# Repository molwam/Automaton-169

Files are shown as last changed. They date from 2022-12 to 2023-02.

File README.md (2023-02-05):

# Automaton 169

This is a wireless low profile split keyboard. It features a 32 key column-staggered and -splayed layout and 3 status LEDs per side. For wireless operation it utilizes a Seeed Studio XIAO nRF52840 running ZMK.

## PCB
Gerber, Kicad Files, BOM and order and assembly instructions are [here](https://github.com/molwam/Automaton-169/tree/main/pcb).

## Firmware
Just flash the left side and right side [fimware ](https://github.com/molwam/zmk-config-automaton-169/tree/main/config) onto the the corresponding side controller. If you want to customize the keymap, clone the repo and adjust the [keymap file](https://github.com/molwam/zmk-config-automaton-169/blob/main/config/boards/shields/automaton169/automaton169.keymap).

## Credits
This keyboard was inspired by the [KLOTZ](https://github.com/GEIGEIGEIST/KLOTZ) by [GEIST](https://github.com/GEIGEIGEIST) and the [midge](https://github.com/jimmerricks/bugs/tree/main/pcbs/midge) by [jmnw](https://github.com/jimmerricks).

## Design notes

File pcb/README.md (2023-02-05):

# PCB
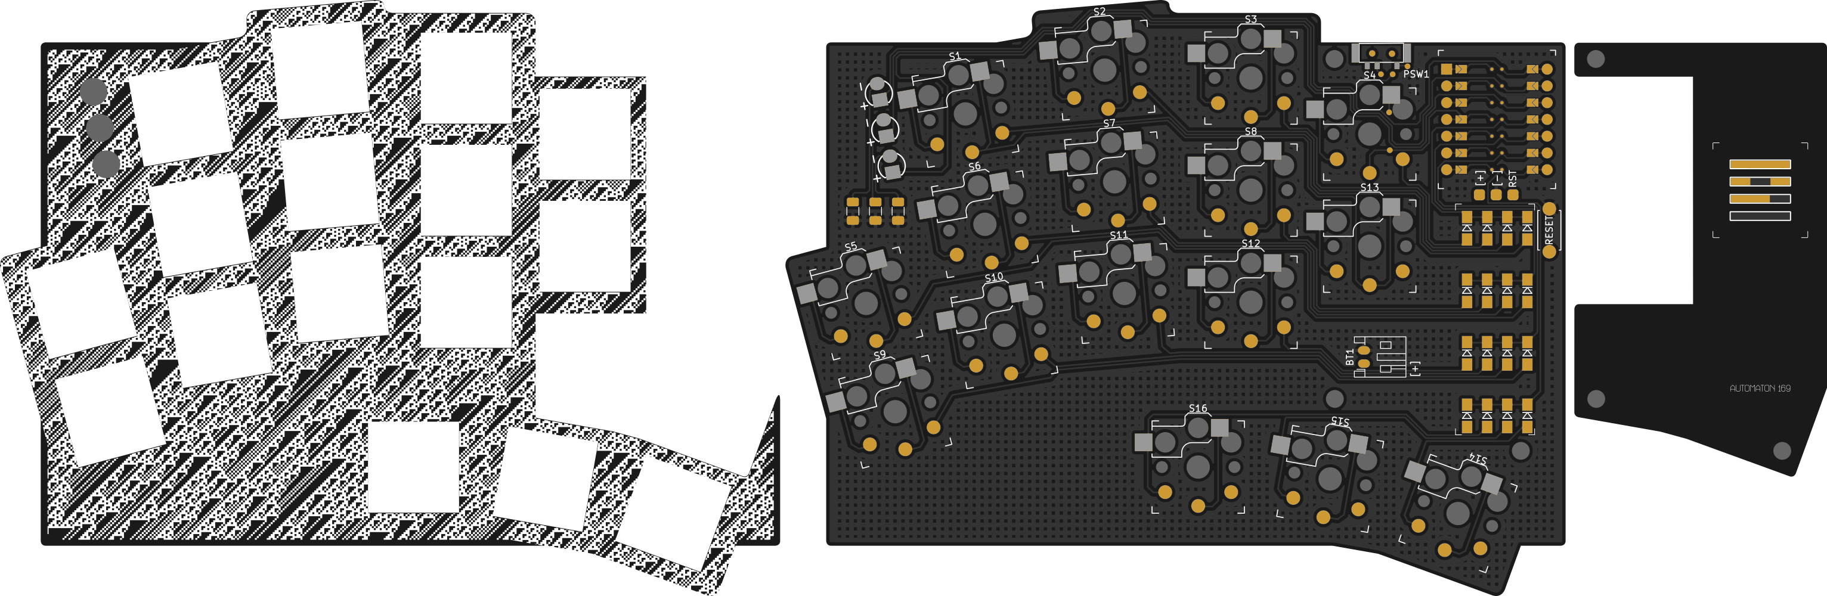
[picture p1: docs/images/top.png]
PCB top

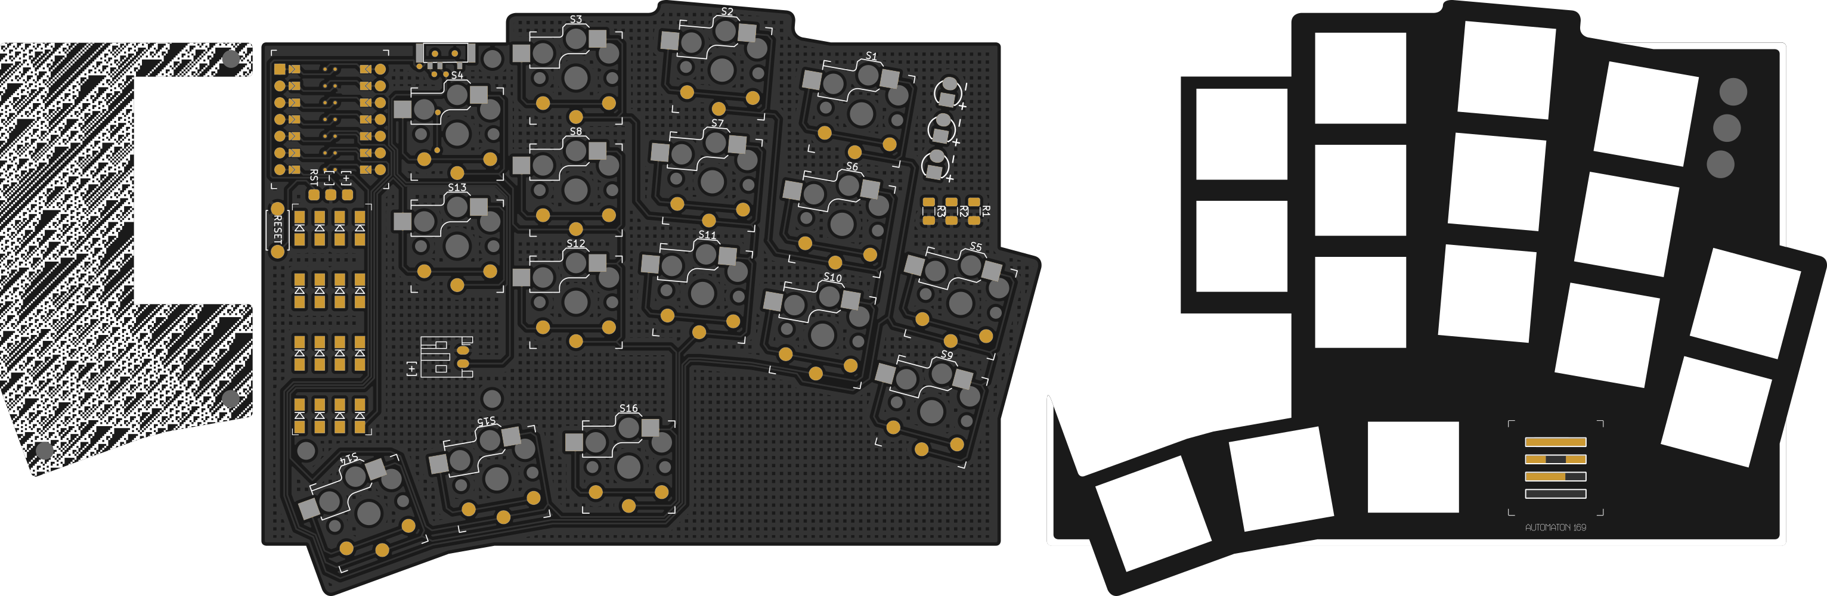
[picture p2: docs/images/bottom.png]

## Ordering

You can use the [gerber.zip](https://github.com/molwam/Automaton-169/blob/main/pcb/gerber.zip) file to order the PCB at your favorite PCB manufacturer. It's reversible so you need to order at least 2. These are the required settings when ordering:

 - Material: FR-4
 - Layers: 2
 - Dimension (Length): 281.40mm
 - Dimension (Width): 90.40mm
 - Separated Different Design: 3*
 - Panelized PCBs: As in my Gerber Files* 
 - PCB Thickness: 1.6mm
 - Copper Thickness: 1 oz
 - Inner Copper Thickness: No
 - FR-4 Material: TG135
 - Min. Traces / Spacing: 6 mil
 - Min. Hole Size: 0.3 mm
 - Edge Plating: No
 - Blind Vias: No
 - Half Cut Holes: No
 - Impedance Control: No

*The PCB is panelized in three Parts: PCB - Switch Plate - Controller and Battery Cover

## Parts needed 

## Assembly

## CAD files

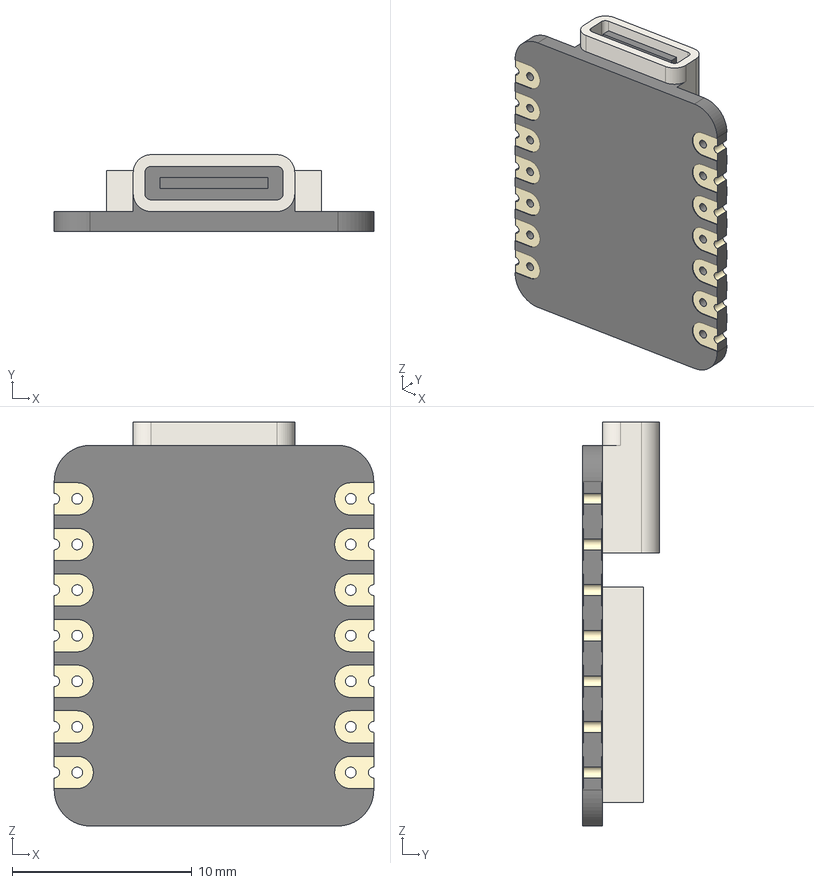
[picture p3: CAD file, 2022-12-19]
pcb/kicad files/3D/xiao-ble-tht.step
17.8 x 4.27 x 22.5 mm

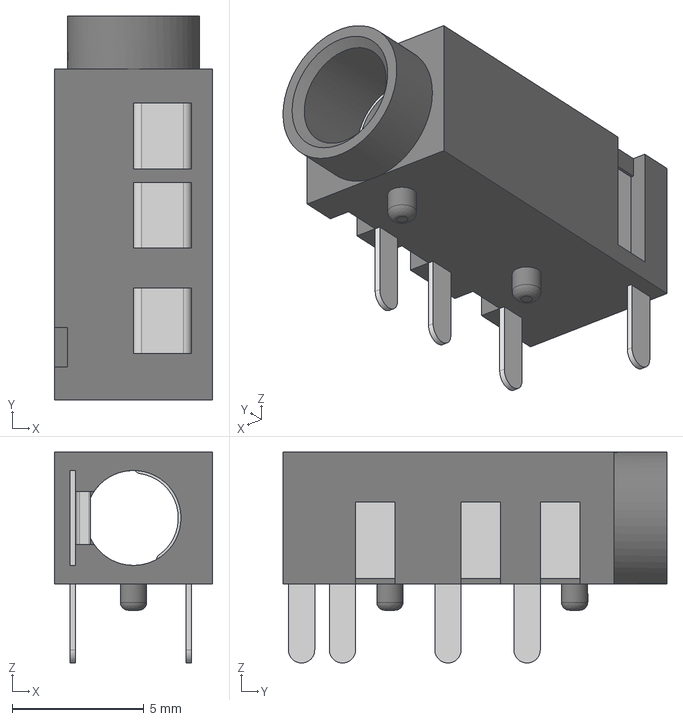
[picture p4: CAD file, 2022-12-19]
pcb/kicad files/3D/PJ320A.STEP
6.00 x 14.6 x 8.00 mm

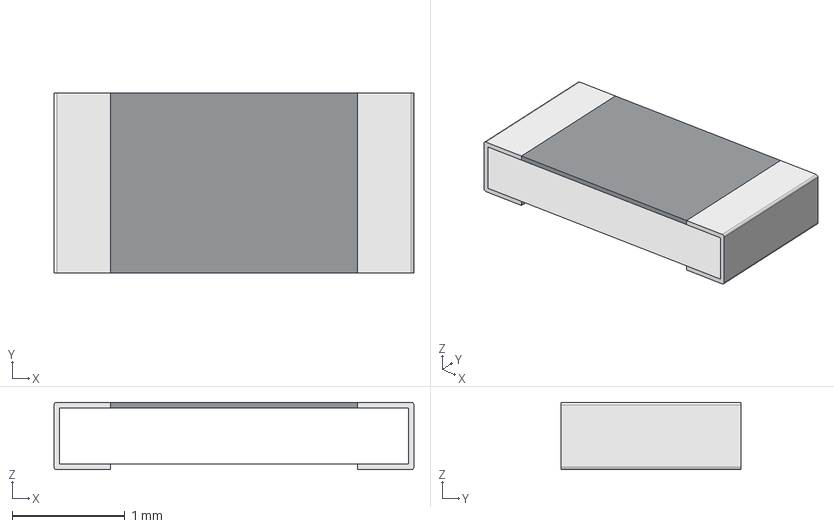
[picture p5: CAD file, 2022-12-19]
pcb/kicad files/3D/R1206 ERJ8EN Thick.step
3.20 x 1.60 x 0.6 mm

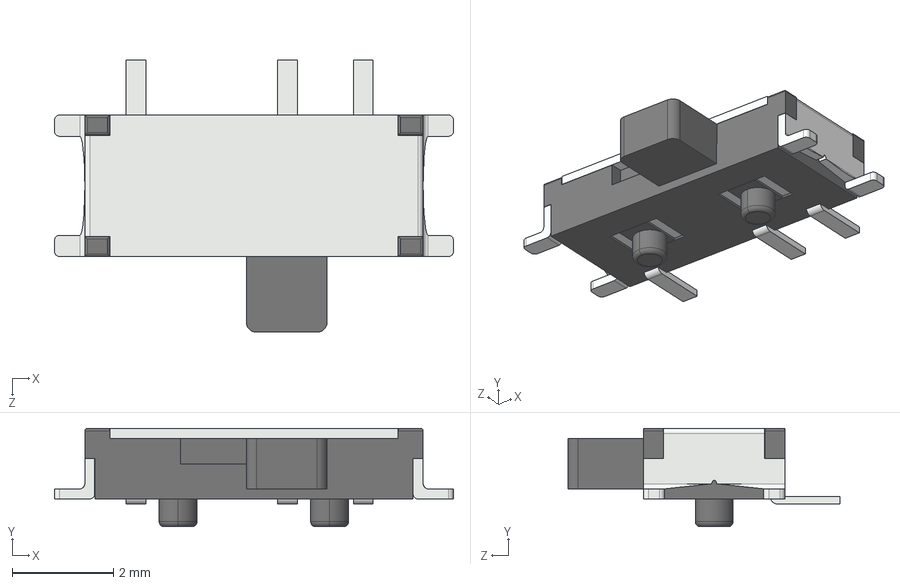
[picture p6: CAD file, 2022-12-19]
pcb/kicad files/3D/MSK12C02.STEP
7.90 x 1.95 x 5.39 mm

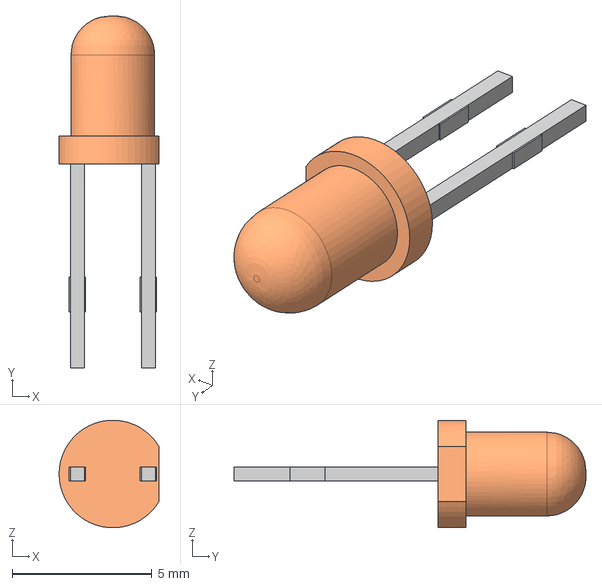
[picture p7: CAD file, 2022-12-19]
pcb/kicad files/3D/LED 3mm Orange.step
3.58 x 12.6 x 3.85 mm

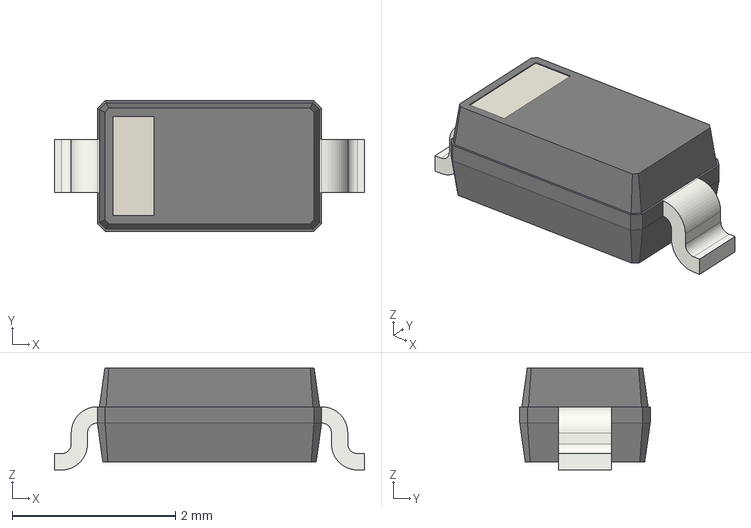
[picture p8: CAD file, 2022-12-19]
pcb/kicad files/3D/D_SOD-123.step
3.80 x 1.60 x 1.25 mm

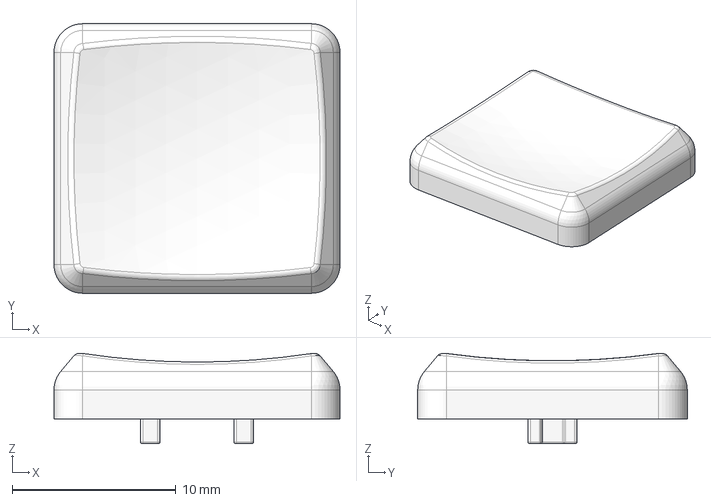
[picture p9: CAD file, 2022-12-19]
pcb/kicad files/3D/MBK_Keycap_-_1u.step
17.4 x 16.4 x 5.52 mm

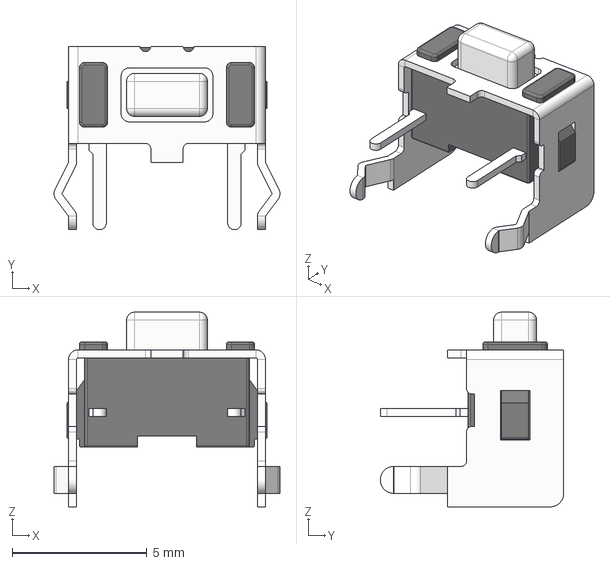
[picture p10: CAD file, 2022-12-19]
pcb/kicad files/3D/SW_SKHLLC.step
8.38 x 6.80 x 7.22 mm

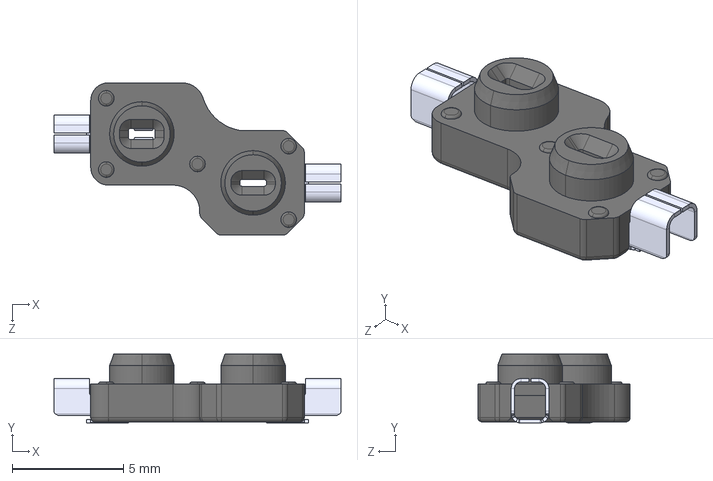
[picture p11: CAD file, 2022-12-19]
pcb/kicad files/3D/Kailh_socket_PG1350_optional.STEP
12.9 x 3.09 x 6.85 mm
pin x 2
socket

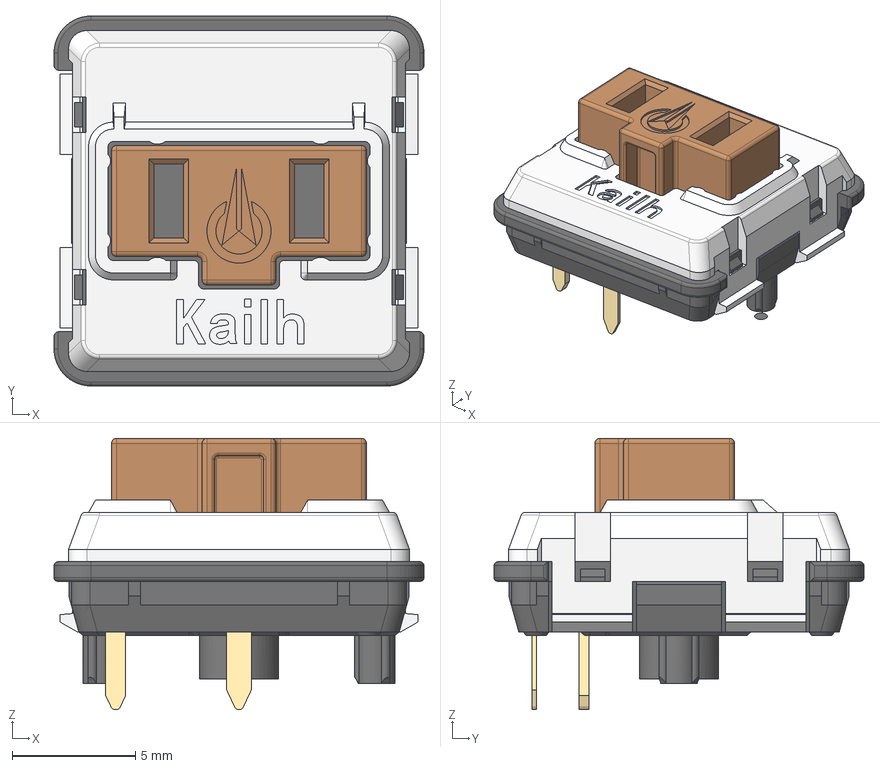
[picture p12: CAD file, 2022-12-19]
pcb/kicad files/3D/Kailh_switch_PG1350_optional.step
15.0 x 15.0 x 11.0 mm

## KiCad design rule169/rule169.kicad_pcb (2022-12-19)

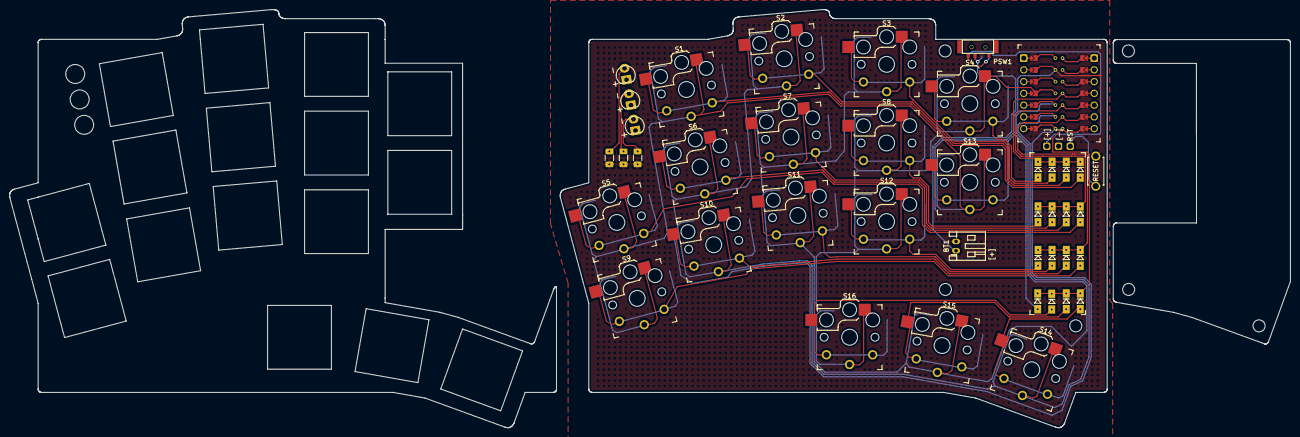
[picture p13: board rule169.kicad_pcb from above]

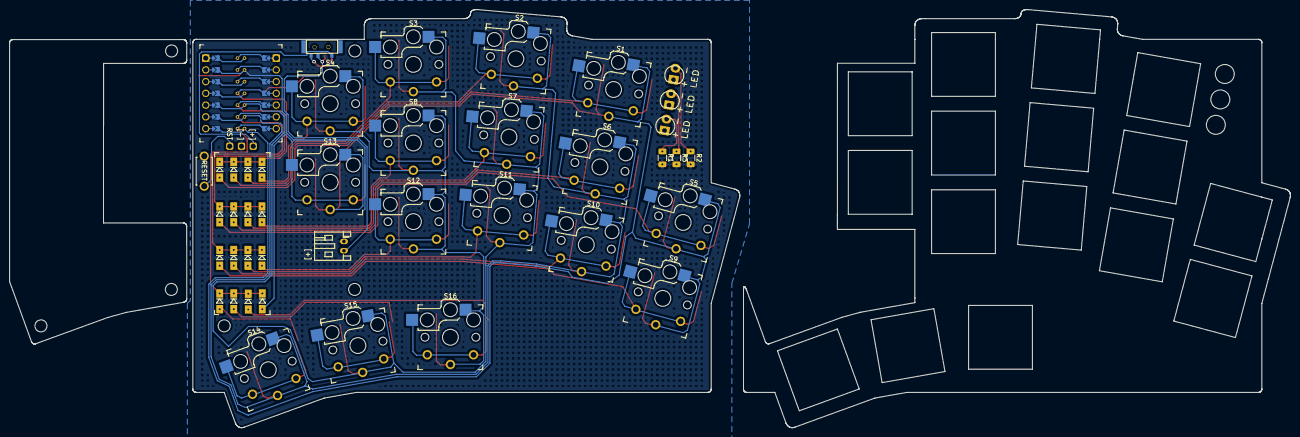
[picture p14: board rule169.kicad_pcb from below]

Board: 2 copper layers, 276.9 x 90.4 mm, 42 parts (3 on the bottom side), 34 nets.

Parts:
BT1: Battery_Cell; JST_PH_reversible
D1, D2, D3, D4, D5, D6, D7, D8, D9, D10, D11, D12, D13, D14, D15, D16: D_Small; Diode_SOD123
L1, L2, L3: LED; LED_3mm_reversible
PSW1: SW_DPDT_x2; MSK12C02_reversible
R1, R2, R3: 220; R_1206_DoubleSided
RSW1: SW_Push; ResetSW
S1, S2, S3, S4, S5, S6, S7, S8, S9, S10, S11, S12, S13, S14, S15, S16: MX_SW_HS; Kailh_socket_PG1350_optional_reversible
U1: xiao-ble; xiao seed ble

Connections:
/PL1: L1.1 (K), R1.1
/PL2: L2.1 (K), R2.1
/PL3: L3.1 (K), R3.1
GND: BT1.2 (-), R1.2, R2.2, R3.2, RSW1.1, U1.13 (GND), U1.20 (GND)
LED0: L1.2 (A), U1.1 (A2/0.02_H)
LED1: L2.2 (A), U1.2 (A4/0.03_H)
LED2: L3.2 (A), U1.3 (A10/0.28)
MCU+: PSW1.1 (A), U1.19 (BAT)
unnamed: BT1.1 (+), PSW1.2 (B)
unnamed: D1.2 (A), S1.2
unnamed: D2.2 (A), S2.2
unnamed: D3.2 (A), S3.2
unnamed: D4.2 (A), S4.2
unnamed: D5.2 (A), S5.2
unnamed: D6.2 (A), S6.2
unnamed: D7.2 (A), S7.2
unnamed: D8.2 (A), S8.2
unnamed: D9.2 (A), S9.2
unnamed: D10.2 (A), S10.2
unnamed: D11.2 (A), S11.2
unnamed: D12.2 (A), S12.2
unnamed: D13.2 (A), S13.2
unnamed: D14.2 (A), S14.2
unnamed: D15.2 (A), S15.2
unnamed: D16.2 (A), S16.2
RESET: RSW1.2, U1.17 (RESET)
col0: S4.1, S8.1, S12.1, S16.1, U1.11 (A6_MOSI/1.15)
col1: S3.1, S7.1, S11.1, S15.1, U1.10 (A5_MISO/1.14)
col2: S2.1, S6.1, S10.1, S14.1, U1.9 (A7_SCK/1.13)
col3: S1.1, S5.1, S9.1, S13.1, U1.8 (B9_RX/1.12)
row0: D1.1 (K), D2.1 (K), D3.1 (K), D4.1 (K), U1.4 (A11/0.29)
row1: D5.1 (K), D6.1 (K), D7.1 (K), D8.1 (K), U1.5 (A8_SDA/0.04_H)
row2: D9.1 (K), D10.1 (K), D11.1 (K), D12.1 (K), U1.6 (A9_SCL/0.05_H)
row3: D13.1 (K), D14.1 (K), D15.1 (K), D16.1 (K), U1.7 (B8_TX/1.11)

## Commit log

2022-11-12 initialize repo
    [rule169.kicad_pcb, rule169.kicad_sch]
2022-12-19 add project files
    [D_SOD-123.step, Kailh_socket_PG1350_optional.STEP, Kailh_switch_PG1350_optional.step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]
2022-12-21 add silkscreen
    [rule169.kicad_sch]
2023-02-04 panelize pcbs
    [D_SOD-123.step, Kailh_socket_PG1350_optional.STEP, Kailh_switch_PG1350_optional.step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]
